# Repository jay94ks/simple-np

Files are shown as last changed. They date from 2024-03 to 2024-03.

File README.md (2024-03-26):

# Simple Number Pad
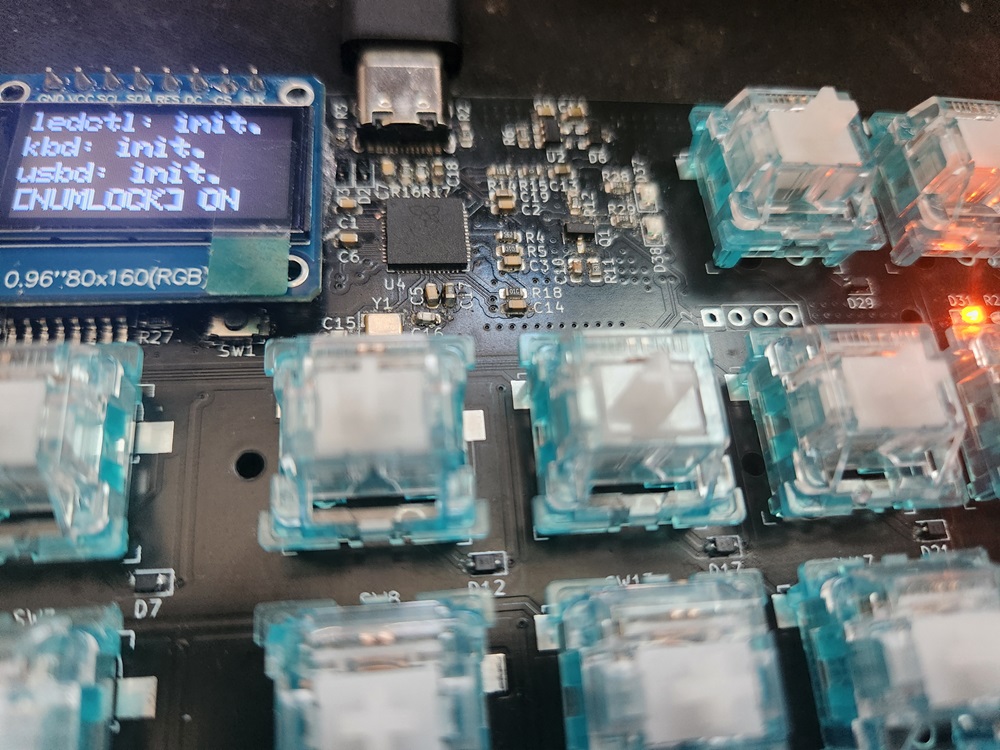
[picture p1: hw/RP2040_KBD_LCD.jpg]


### License
* This repository: MIT, partially GPL-v3 due to TFT library.
* TFT library: GPL-v3, [ST7735_TFT_PICO](https://github.com/gavinlyonsrepo/ST7735_TFT_PICO)

### Video


### Schematic
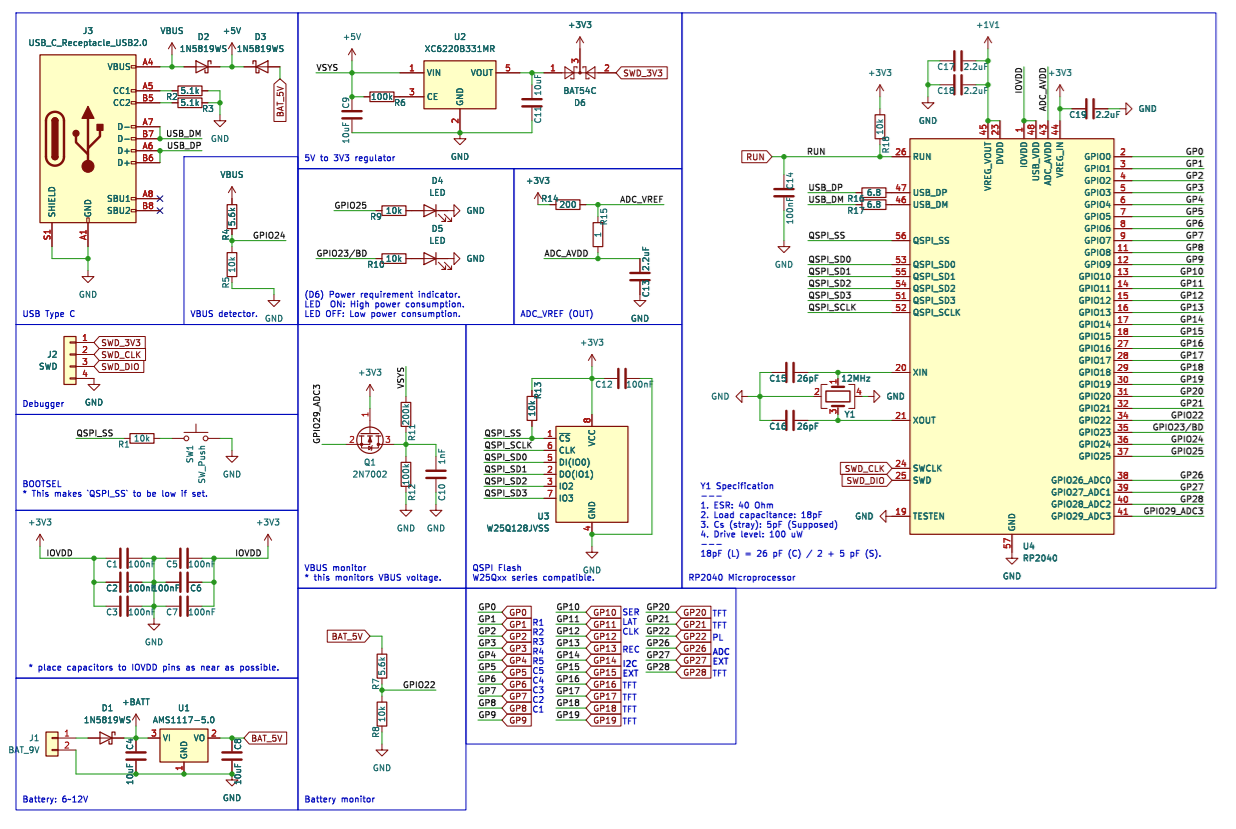
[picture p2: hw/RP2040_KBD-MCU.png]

See `hw/pdf/*.pdf` files to read more details.

### Features
* MCU: RP2040, 133MHz Dual core.
* 5 keys for user-defined functions.
* 17 keys for number pad.
* `TFT` display for calculator if no `HID` attached.
* 2 macro control keys, `RECORD` and `PLAY`.

### Plans for future features
* A flash memory to store user configurations? (currently, they're stored at `SRAM` of MCU only, so, volatile)
* I2C or SPI extension port?
* A little game that runs on the `TFT` display?
* Anything else...

### Firmware
Current planed features are implemented.
Now, calculator mode will be implemented soon.

### `tinyusb` RX callback.
Don't use `0.15.0` distribution that included on `pico-sdk`.
Update its branch to above version, then it works perfectly.

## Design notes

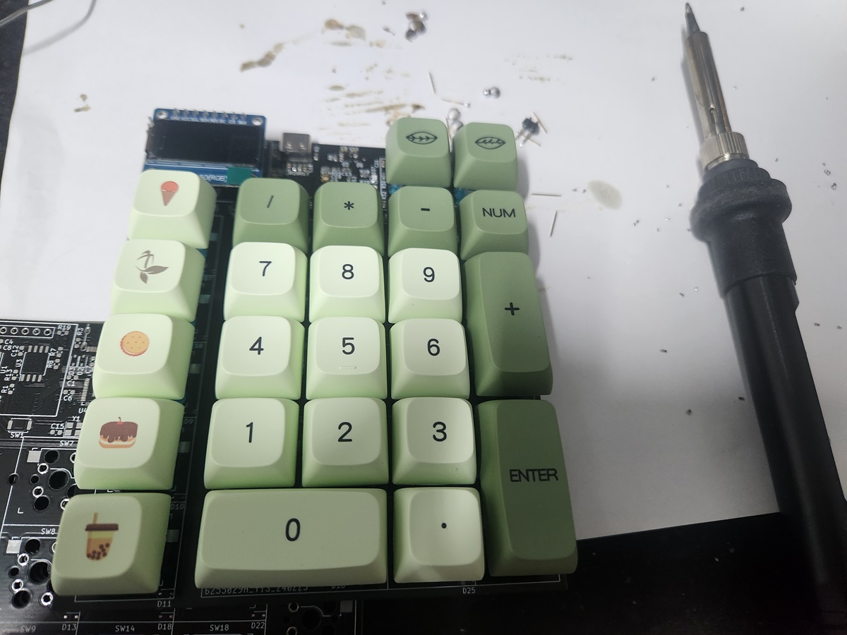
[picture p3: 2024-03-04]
hw/RP2040_KBD-IMG.jpg

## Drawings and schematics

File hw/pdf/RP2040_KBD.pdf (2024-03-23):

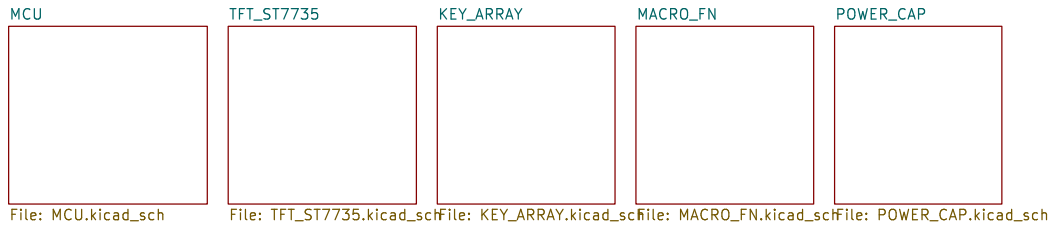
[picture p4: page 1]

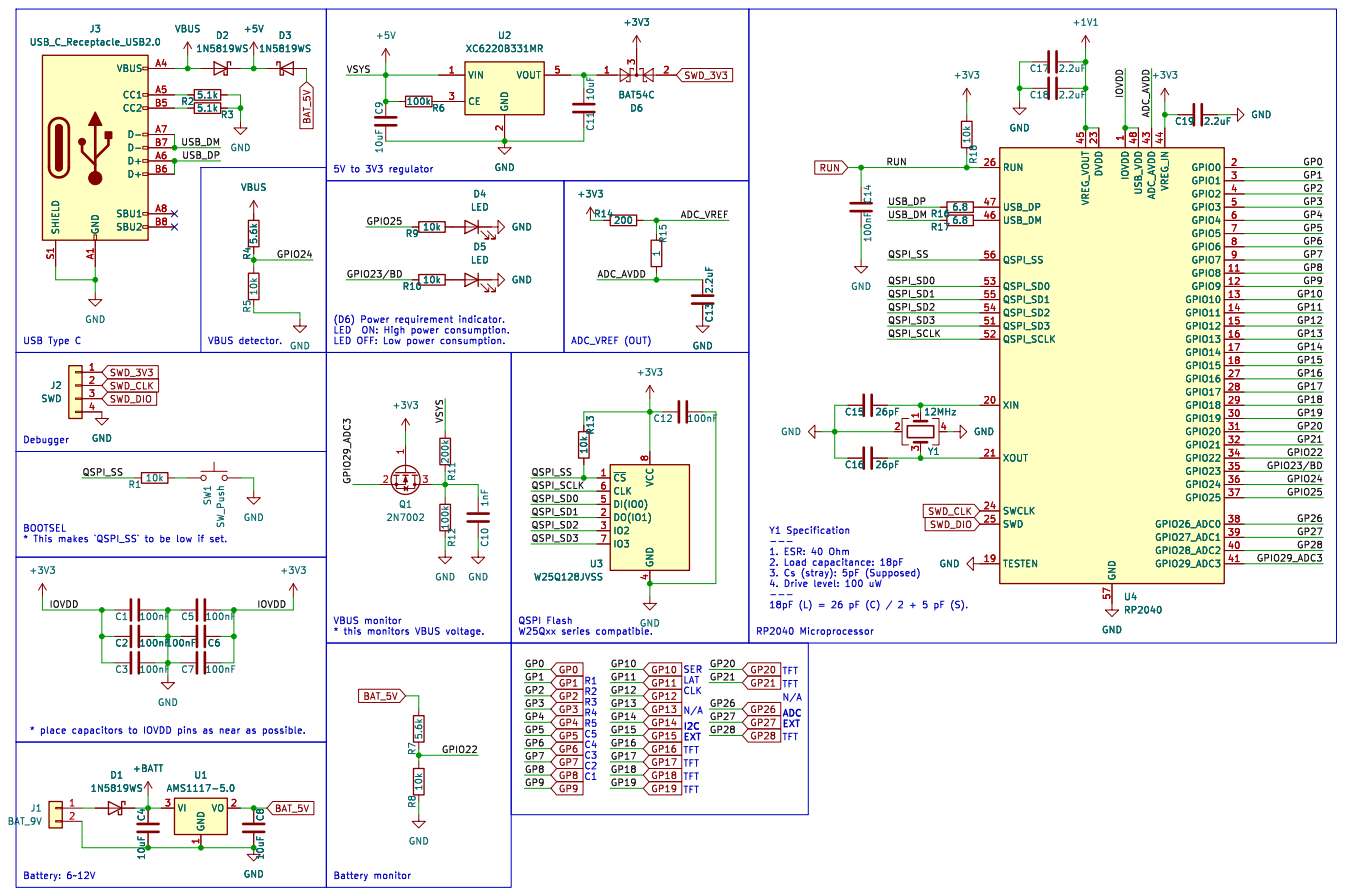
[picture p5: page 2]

1 GPIO8 11 GPIO9 12 GPIO10 13 GPIO11 14 GPIO12 15 GPIO13 16 GPIO14 17 GPIO15 18 TESTEN 19 GPIO0 2 XIN 20 XOUT 21 DVDD 23 SWCLK 24 SWD 25 RUN 26 GPIO16 27 GPIO17 28 GPIO18 29 GPIO1 3 GPIO19 30 GPIO20 31 GPIO21 32 GPIO22 34 GPIO23 35 GPIO24 36 GPIO25 37 GPIO26_ADC0 38 GPIO27_ADC1 39 GPIO2 4 GPIO28_ADC2 40 GPIO29_ADC3 41 ADC_AVDD 43 VREG_IN 44 VREG_VOUT 45 USB_DM 46 USB_DP 47 USB_VDD 48 GPIO3 5 QSPI_SD3 51 QSPI_SCLK 52 QSPI_SD0 53 QSPI_SD2 54 QSPI_SD1 55 QSPI_SS 56 GND 57 GPIO4 6 GPIO5 7 GPIO6 8 GPIO7 9 U4 RP2040 D1

1 GPIO8 11 GPIO9 12 GPIO10 13 GPIO11 14 GPIO12 15 GPIO13 16 GPIO14 17 GPIO15 18 TESTEN 19 GPIO0 2 XIN 20 XOUT 21 DVDD 23 SWCLK 24 SWD 25 RUN 26 GPIO16 27 GPIO17 28 GPIO18 29 GPIO1 3 GPIO19 30 GPIO20 31 GPIO21 32 GPIO22 34 GPIO23 35 GPIO24 36 GPIO25 37 GPIO26_ADC0 38 GPIO27_ADC1 39 GPIO2 4 GPIO28_ADC2 40 GPIO29_ADC3 41 ADC_AVDD 43 VREG_IN 44 VREG_VOUT 45 USB_DM 46 USB_DP 47 USB_VDD 48 GPIO3 5 QSPI_SD3 51 QSPI_SCLK 52 QSPI_SD0 53 QSPI_SD2 54 QSPI_SD1 55 QSPI_SS 56 GND 57 GPIO4 6 GPIO5 7 GPIO6 8 GPIO7 9 GND GND

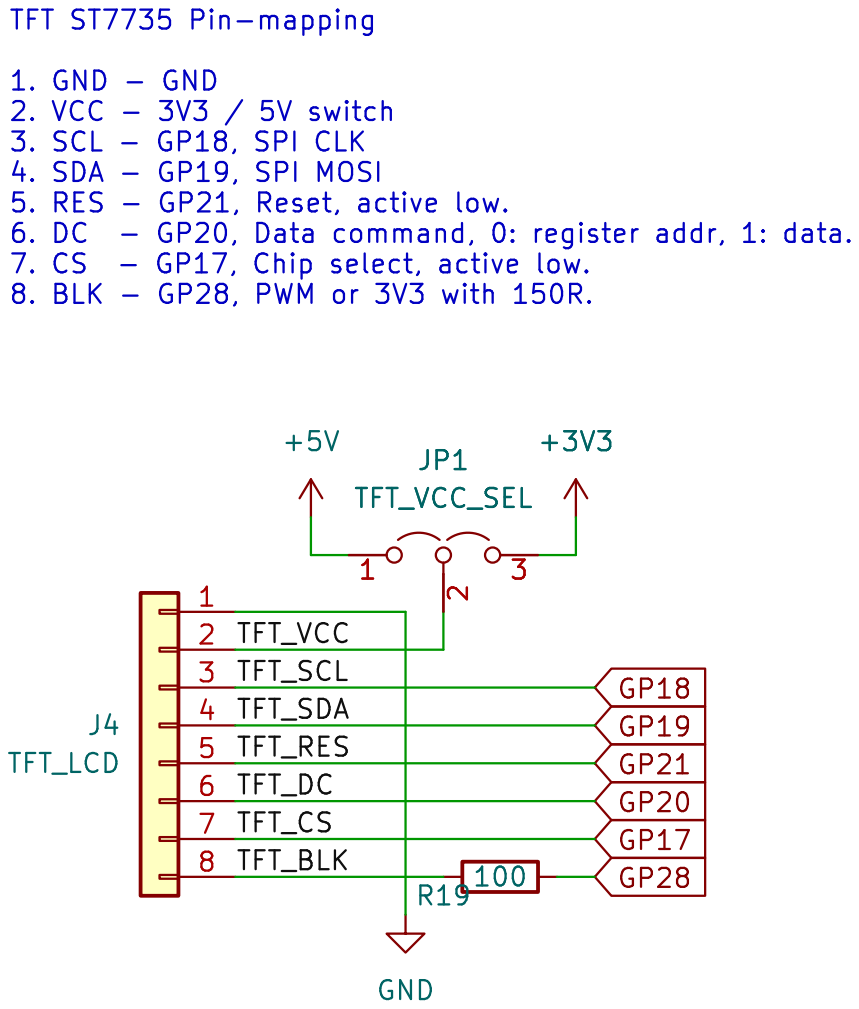
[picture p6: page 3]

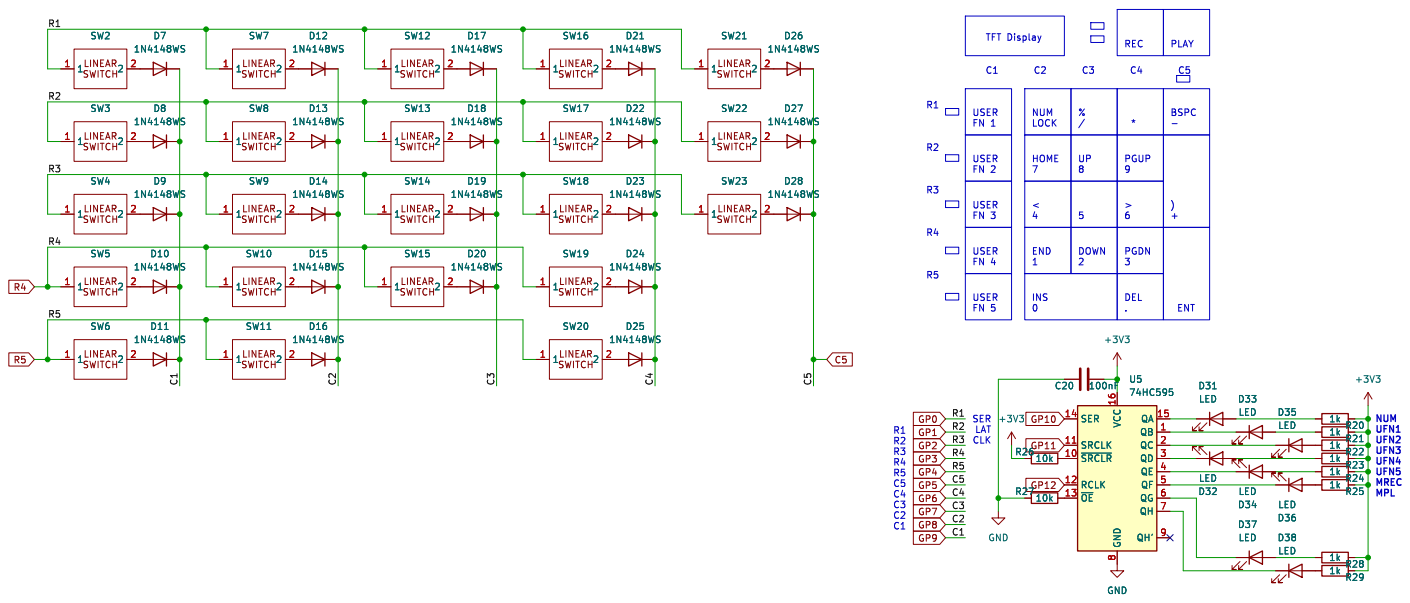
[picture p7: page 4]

BSPC - ENT DEL . USER

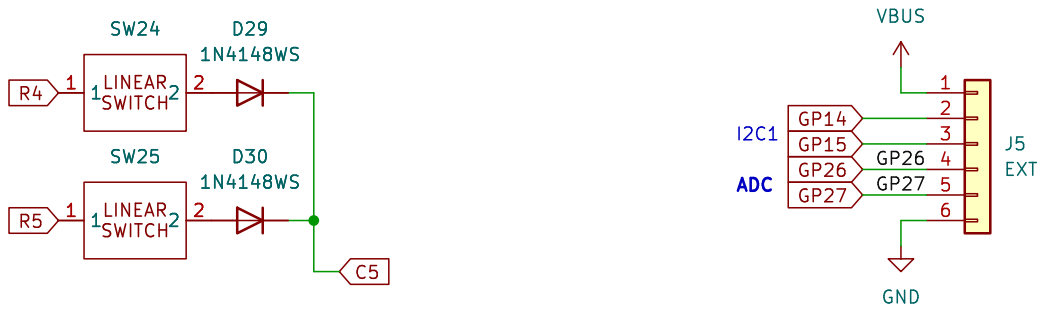
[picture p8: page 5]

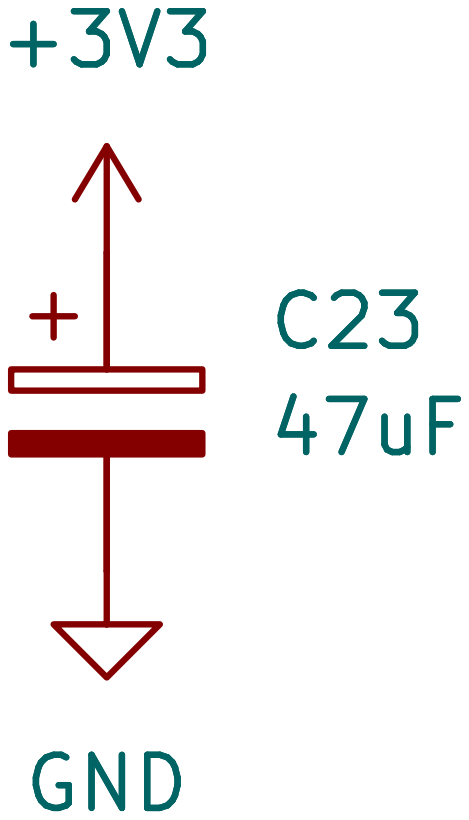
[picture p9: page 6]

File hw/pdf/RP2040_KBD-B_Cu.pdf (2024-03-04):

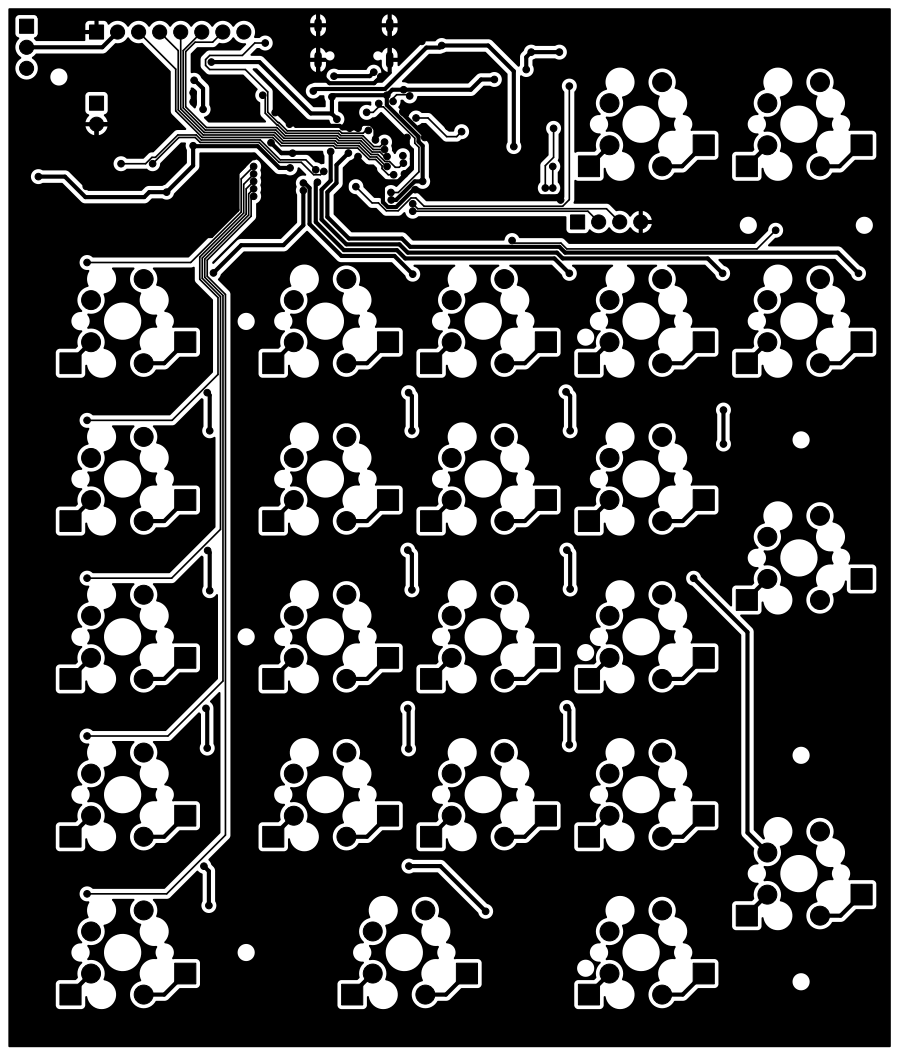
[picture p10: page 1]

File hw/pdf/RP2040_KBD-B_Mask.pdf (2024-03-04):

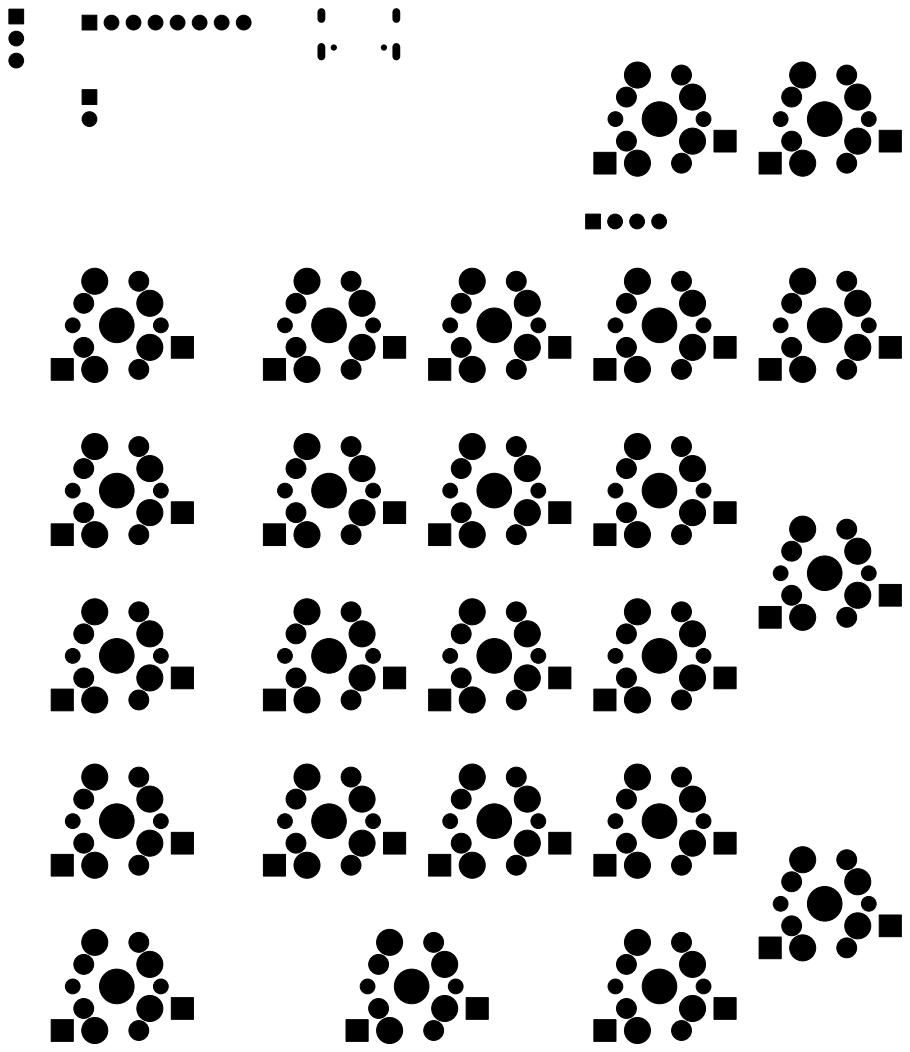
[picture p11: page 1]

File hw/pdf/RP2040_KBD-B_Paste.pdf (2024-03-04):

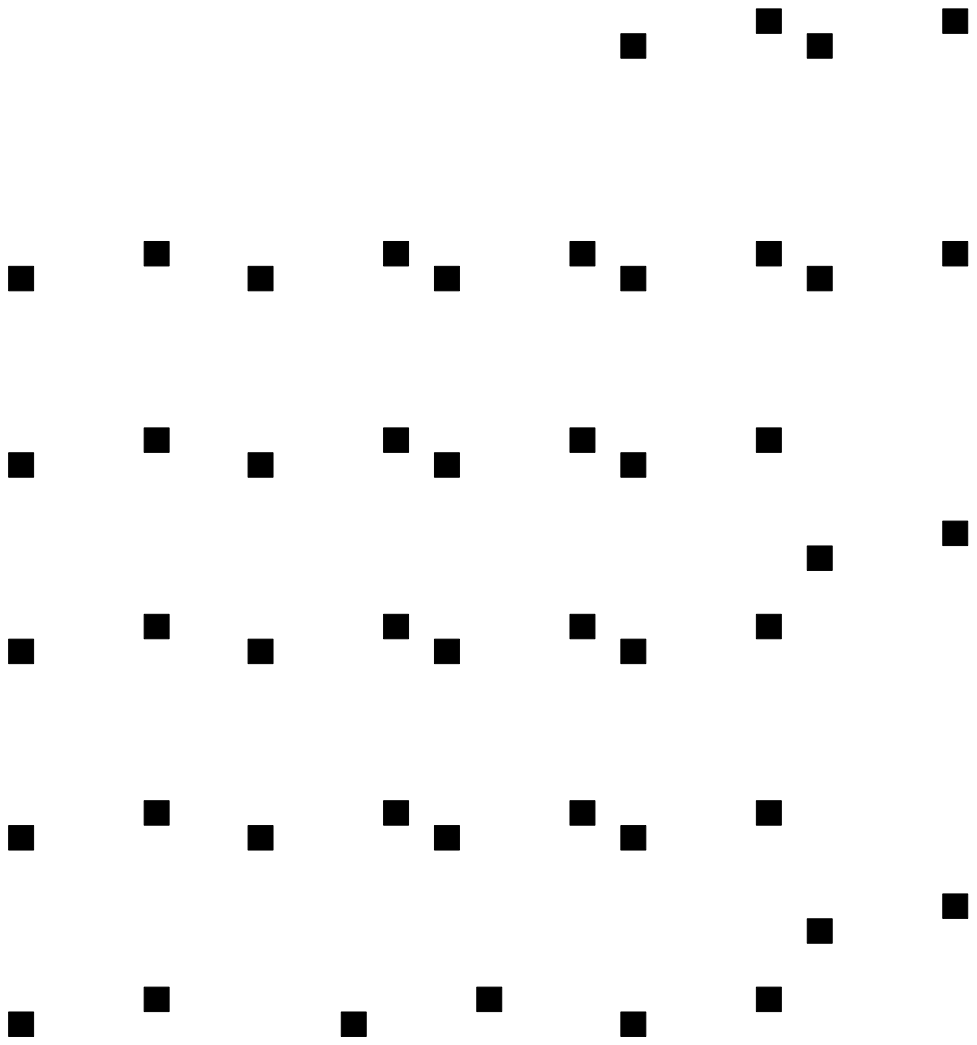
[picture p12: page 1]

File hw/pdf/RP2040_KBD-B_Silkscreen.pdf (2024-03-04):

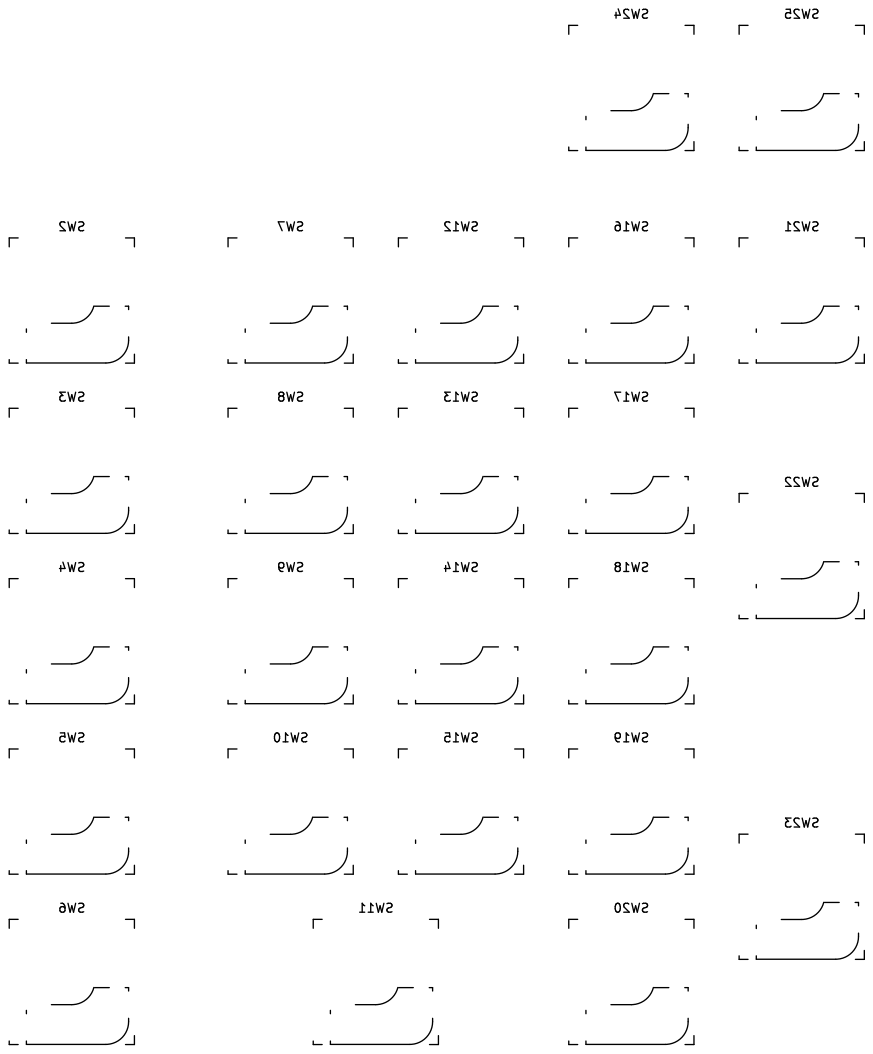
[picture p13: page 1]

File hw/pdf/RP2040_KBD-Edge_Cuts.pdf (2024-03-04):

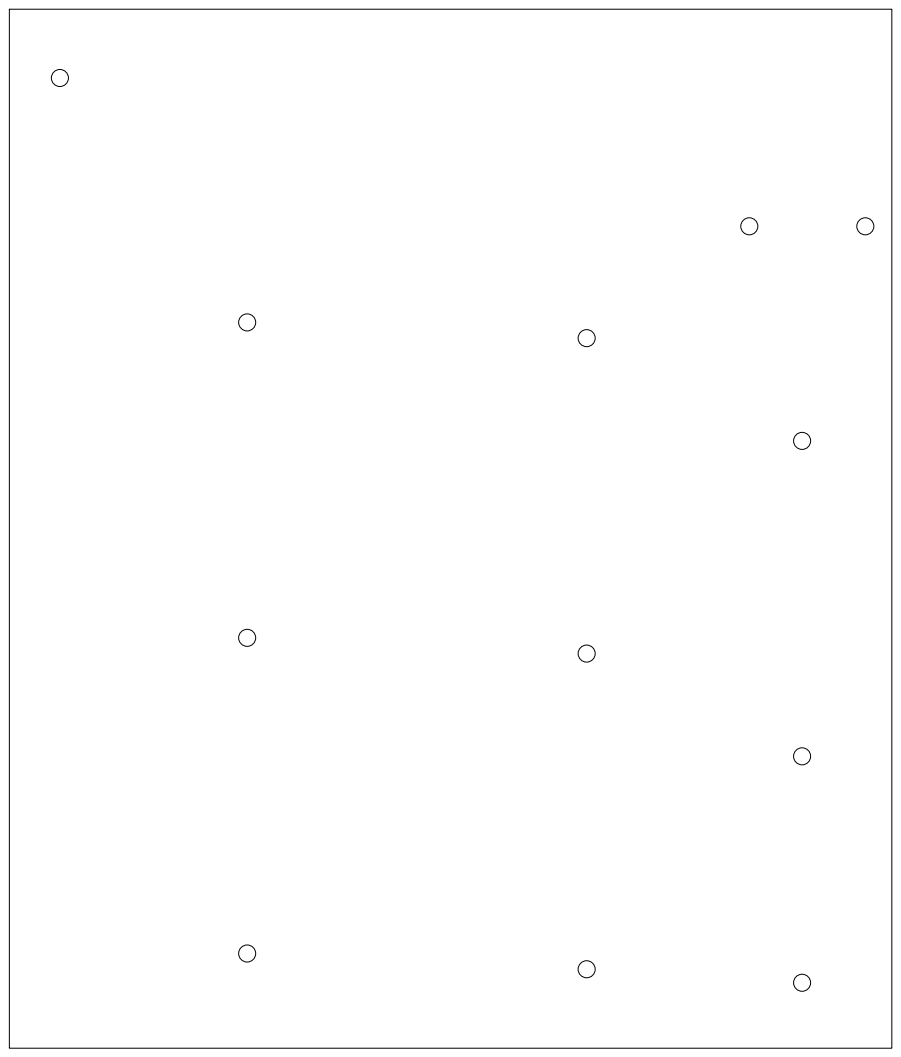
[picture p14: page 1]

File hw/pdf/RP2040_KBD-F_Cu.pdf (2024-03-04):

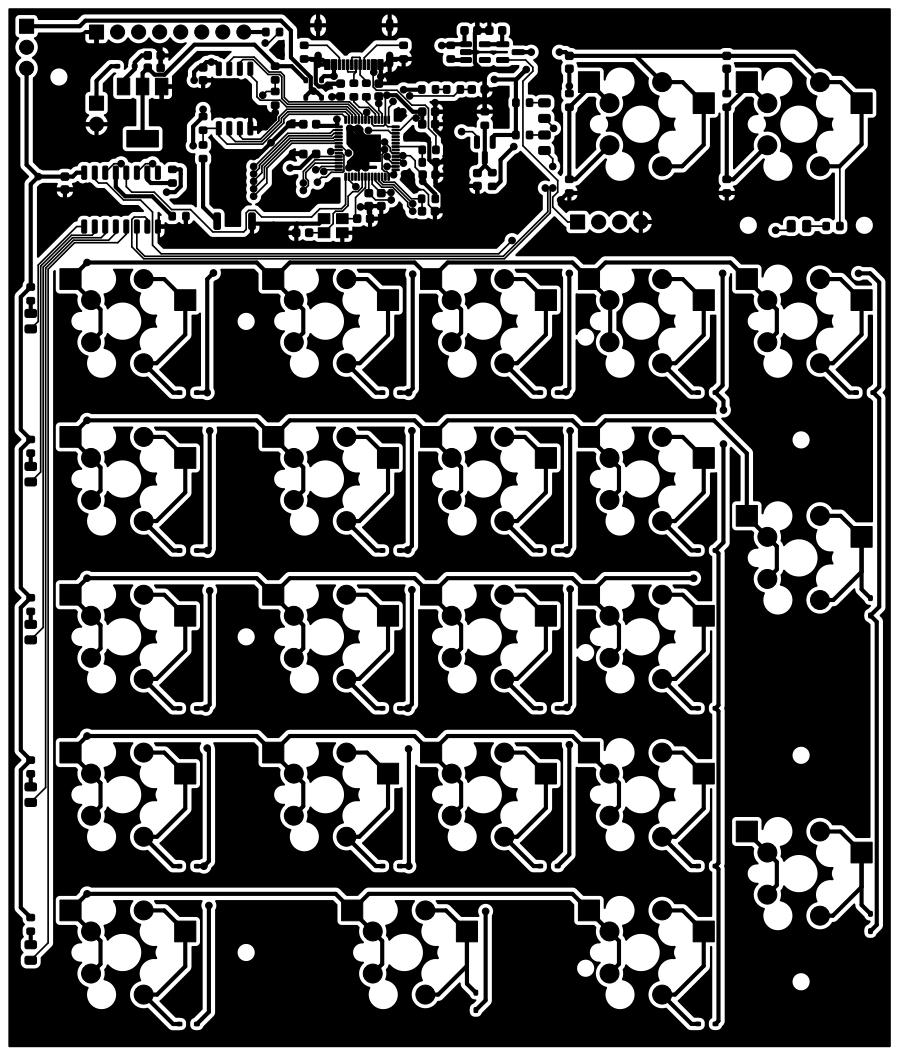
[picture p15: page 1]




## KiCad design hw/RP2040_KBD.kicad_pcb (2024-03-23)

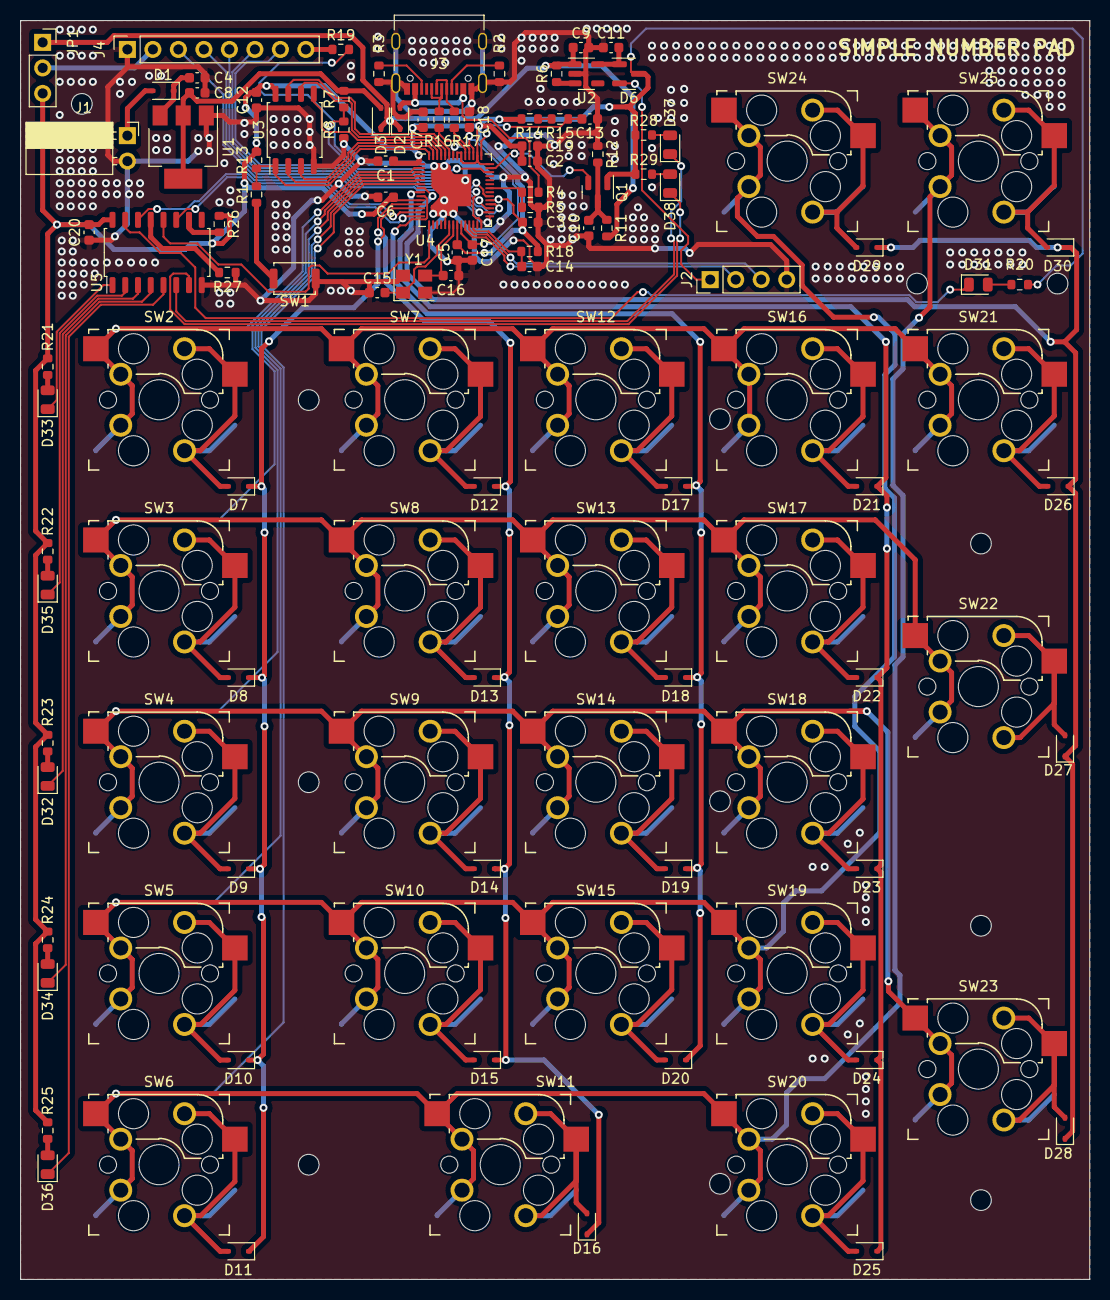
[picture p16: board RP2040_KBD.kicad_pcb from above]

Board: 2 copper layers, 106.5 x 125.4 mm, 120 parts (0 on the bottom side), 98 nets.

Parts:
C1, C2, C3, C5, C6, C7, C12, C14, C20: 100nF; C_0603_1608Metric
C4, C8, C9, C11: 10uF; C_0603_1608Metric
C10: 1nF; C_0603_1608Metric
C13, C17, C18, C19: 2.2uF; C_0603_1608Metric
C15, C16: 26pF; C_0603_1608Metric
D1, D2, D3: 1N5819WS; D_SOD-323
D6: BAT54C; SOT-23
D7, D8, D9, D10, D11, D12, D13, D14, D15, D16, D17, D18, D19, D20, D21, D22, D23, D24, D25, D26, D27, D28, D29, D30: 1N4148WS; D_SOD-323
D31, D32, D33, D34, D35, D36, D37, D38: LED; LED_0805_2012Metric
J1: BAT_9V; PinSocket_1x02_P2.54mm_Horizontal
J2: SWD; PinHeader_1x04_P2.54mm_Vertical
J3: USB_C_Receptacle_USB2.0; USB_C_Receptacle_Palconn_UTC16-G
J4: TFT_LCD; PinSocket_1x08_P2.54mm_Vertical
JP1: TFT_VCC_SEL; PinSocket_1x03_P2.54mm_Vertical
Q1: 2N7002; SOT-23
R1, R5, R8, R13, R18, R26, R27: 10k; R_0603_1608Metric
R2, R3: 5.1k; R_0603_1608Metric
R4, R7: 5.6k; R_0603_1608Metric
R6, R12: 100k; R_0603_1608Metric
R11: 200k; R_0603_1608Metric
R14: 200; R_0603_1608Metric
R15: 1; R_0603_1608Metric
R16, R17: 6.8; R_0603_1608Metric
R19: 100; R_0603_1608Metric
R20, R21, R22, R23, R24, R25, R28, R29: 1k; R_0603_1608Metric
SW1: SW_Push; SW_Push_SPST_NO_Alps_SKRK
SW2, SW3, SW4, SW5, SW6, SW7, SW8, SW9, SW10, SW11, SW12, SW13, SW14, SW15, SW16, SW17, SW18, SW19, SW20, SW21, SW22, SW23, SW24, SW25: Kailh_socket_MX_optional_reversible
U1: AMS1117-5.0; SOT-223-3_TabPin2
U2: XC6220B331MR; SOT-23-5
U3: W25Q128JVSS; SOIC-8_5.23x5.23mm_P1.27mm
U4: RP2040; QFN-56-1EP_7x7mm_P0.4mm_EP3.2x3.2mm
U5: 74HC595; SOP-16_4.55x10.3mm_P1.27mm
Y1: 12MHz; Crystal_SMD_3225-4Pin_3.2x2.5mm

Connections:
+1V1: C17.2, C18.2, U4.23 (DVDD), U4.45 (VREG_VOUT), U4.50 (DVDD)
+3V3: C1.1, C2.1, C3.1, C5.1, C6.1, C7.1, C12.1, C19.1, C20.2, D6.3, JP1.3 (B), Q1.1 (G), R13.1, R14.1, R18.2, R20.1, R21.1, R22.1, R23.1, R24.1, R25.1, R26.1, R28.1, R29.1, U3.8 (VCC), U4.1 (IOVDD), U4.10 (IOVDD), U4.22 (IOVDD), U4.33 (IOVDD), U4.42 (IOVDD), U4.44 (VREG_IN), U4.48 (USB_VDD), U4.49 (IOVDD), U5.16 (VCC)
+5V: C9.1, D2.1 (K), D3.1 (K), JP1.1 (A), R6.2, R11.2, U2.1 (VIN)
+BATT: C4.1, D1.1 (K), U1.3 (VI)
/MCU/ADC_AVDD: C13.2, R15.2, U4.43 (ADC_AVDD)
/MCU/ADC_VREF: R14.2, R15.1
/MCU/GPIO22: R7.1, R8.2, U4.34 (GPIO22)
/MCU/GPIO24: R4.1, R5.2, U4.36 (GPIO24)
/MCU/GPIO29_ADC3: Q1.2 (S), U4.41 (GPIO29_ADC3)
/MCU/QSPI_SCLK: U3.6 (CLK), U4.52 (QSPI_SCLK)
/MCU/QSPI_SD0: U3.5 (DI(IO0)), U4.53 (QSPI_SD0)
/MCU/QSPI_SD1: U3.2 (DO(IO1)), U4.55 (QSPI_SD1)
/MCU/QSPI_SD2: U3.3 (IO2), U4.54 (QSPI_SD2)
/MCU/QSPI_SD3: U3.7 (IO3), U4.51 (QSPI_SD3)
/MCU/QSPI_SS: R1.1, R13.2, U3.1 (~CS), U4.56 (QSPI_SS)
/MCU/USB_DM: J3.A7 (D-), J3.B7 (D-), R17.1
/MCU/USB_DP: J3.A6 (D+), J3.B6 (D+), R16.1
/TFT_ST7735/TFT_BLK: J4.8, R19.1
/TFT_ST7735/TFT_VCC: J4.2, JP1.2 (C)
BAT_5V: C8.1, D3.2 (A), R7.2, U1.2 (VO)
C5: D26.1 (K), D27.1 (K), D28.1 (K), D29.1 (K), D30.1 (K), U4.7 (GPIO5)
GND: C1.2, C2.2, C3.2, C4.2, C5.2, C6.2, C7.2, C8.2, C9.2, C10.1, C11.1, C12.2, C13.1, C14.2, C15.1, C16.1, C17.1, C18.1, C19.2, C20.1, J1.2, J2.4, J3.A1 (GND), J3.A12 (GND), J3.B1 (GND), J3.B12 (GND), J3.S1 (SHIELD), J4.1, R2.2, R3.1, R5.1, R8.1, R12.1, R27.1, SW1.1, U1.1 (GND), U2.2 (GND), U3.4 (GND), U4.19 (TESTEN), U4.57 (GND), U5.8 (GND), Y1.2, Y1.4
GP0: SW2.1, SW7.1, SW12.1, SW16.1, SW21.1, U4.2 (GPIO0)
GP1: SW3.1, SW8.1, SW13.1, SW17.1, SW22.1, U4.3 (GPIO1)
GP2: SW4.1, SW9.1, SW14.1, SW18.1, SW23.1, U4.4 (GPIO2)
GP3: SW5.1, SW10.1, SW15.1, SW19.1, SW24.1, U4.5 (GPIO3)
GP4: SW6.1, SW11.1, SW20.1, SW25.1, U4.6 (GPIO4)
GP6: D21.1 (K), D22.1 (K), D23.1 (K), D24.1 (K), D25.1 (K), U4.8 (GPIO6)
GP7: D17.1 (K), D18.1 (K), D19.1 (K), D20.1 (K), U4.9 (GPIO7)
GP8: D12.1 (K), D13.1 (K), D14.1 (K), D15.1 (K), D16.1 (K), U4.11 (GPIO8)
GP9: D7.1 (K), D8.1 (K), D9.1 (K), D10.1 (K), D11.1 (K), U4.12 (GPIO9)
GP10: U4.13 (GPIO10), U5.14 (SER)
GP11: U4.14 (GPIO11), U5.11 (SRCLK)
GP12: U4.15 (GPIO12), U5.12 (RCLK)
GP17: J4.7, U4.28 (GPIO17)
GP18: J4.3, U4.29 (GPIO18)
GP19: J4.4, U4.30 (GPIO19)
GP20: J4.6, U4.31 (GPIO20)
GP21: J4.5, U4.32 (GPIO21)
GP28: R19.2, U4.40 (GPIO28_ADC2)
unnamed: D1.2 (A), J1.1
unnamed: D7.2 (A), SW2.2
unnamed: D8.2 (A), SW3.2
unnamed: D9.2 (A), SW4.2
unnamed: D10.2 (A), SW5.2
unnamed: D11.2 (A), SW6.2
unnamed: D12.2 (A), SW7.2
unnamed: D13.2 (A), SW8.2
unnamed: D14.2 (A), SW9.2
unnamed: D15.2 (A), SW10.2
unnamed: D16.2 (A), SW11.2
unnamed: D17.2 (A), SW12.2
unnamed: D18.2 (A), SW13.2
unnamed: D19.2 (A), SW14.2
unnamed: D20.2 (A), SW15.2
unnamed: D21.2 (A), SW16.2
unnamed: D22.2 (A), SW17.2
unnamed: D23.2 (A), SW18.2
unnamed: D24.2 (A), SW19.2
unnamed: D25.2 (A), SW20.2
unnamed: D26.2 (A), SW21.2
unnamed: D27.2 (A), SW22.2
unnamed: D28.2 (A), SW23.2
unnamed: D29.2 (A), SW24.2
unnamed: D30.2 (A), SW25.2
unnamed: D31.2 (A), R20.2
unnamed: D31.1 (K), U5.15 (QA)
unnamed: D32.2 (A), R23.2
unnamed: D32.1 (K), U5.3 (QD)
unnamed: D33.2 (A), R21.2
unnamed: D33.1 (K), U5.1 (QB)
unnamed: D34.2 (A), R24.2
unnamed: D34.1 (K), U5.4 (QE)
unnamed: D35.2 (A), R22.2
unnamed: D35.1 (K), U5.2 (QC)
unnamed: D36.2 (A), R25.2
unnamed: D36.1 (K), U5.5 (QF)
unnamed: D37.2 (A), R28.2
unnamed: D37.1 (K), U5.6 (QG)
unnamed: D38.2 (A), R29.2
unnamed: D38.1 (K), U5.7 (QH)
unnamed: J3.A5 (CC1), R2.1
unnamed: J3.B5 (CC2), R3.2
unnamed: C10.2, Q1.3 (D), R11.1, R12.2
unnamed: R1.2, SW1.2
unnamed: R6.1, U2.3 (CE)
unnamed: C11.2, D6.1, U2.5 (VOUT)
unnamed: R17.2, U4.46 (USB_DM)
unnamed: R16.2, U4.47 (USB_DP)
unnamed: C15.2, U4.20 (XIN), Y1.1
unnamed: C16.2, U4.21 (XOUT), Y1.3
unnamed: R27.2, U5.13 (~OE)
unnamed: R26.2, U5.10 (~SRCLR)
RUN: C14.1, R18.1, U4.26 (RUN)
SWD_3V3: D6.2, J2.1
SWD_CLK: J2.2, U4.24 (SWCLK)
SWD_DIO: J2.3, U4.25 (SWD)
VBUS: D2.2 (A), J3.A4 (VBUS), J3.A9 (VBUS), J3.B4 (VBUS), J3.B9 (VBUS), R4.2

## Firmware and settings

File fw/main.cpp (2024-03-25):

#include "kbd/kbd.h"
#include "tft/tft.h"
#include "board/ledctl.h"
#include "board/usbd.h"
#include "task/taskqueue.h"
#include "mode/mode.h"
#include "pico/stdlib.h"
#include <tusb.h>

int main(void) {
    tty_print("tft: init.\n");
    TaskQueue::prepare();

    Kbd* kbd = Kbd::get();
    tty_print("kbd: init.\n");

    Ledctl* led = Ledctl::get();
    tty_print("led: init.\n");

    Usbd* usbd = Usbd::get();
    if (!usbd->init()) {
        tty_print("usb: fatal.\n");
        
        while(true) {
            led->toggle(ELED_MREC);
            sleep_ms(250);
        }
    }

    // --> try to enter default mode.
    IMode::trySetCurrent(nullptr);
    while(true) {
        kbd->scanOnce();
        led->updateOnce();
        usbd->stepOnce();
        
        // --> calls mode-specific stepper routine.
        if (IMode* mode = IMode::getCurrent()) {
            mode->stepOnce();
        }
    }
}

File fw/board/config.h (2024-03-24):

#ifndef __BOARD_CONFIG_H__
#define __BOARD_CONFIG_H__

// --> report ID for keyboard.
#define RID_KEYBOARD 1

enum {

    GPIO_KBD_ROW_1 = 0,
    GPIO_KBD_ROW_2 = 1,
    GPIO_KBD_ROW_3 = 2,
    GPIO_KBD_ROW_4 = 3,
    GPIO_KBD_ROW_5 = 4,

    GPIO_KBD_COL_5 = 5,
    GPIO_KBD_COL_4 = 6,
    GPIO_KBD_COL_3 = 7,
    GPIO_KBD_COL_2 = 8,
    GPIO_KBD_COL_1 = 9,

    GPIO_HC595_SER = 10,
    GPIO_HC595_CLK = 11,
    GPIO_HC595_LAT = 12,

    GPIO_TFT_RST = 21,
    GPIO_TFT_DC = 20,
    GPIO_TFT_CS = 17,
    GPIO_TFT_CLK = 18,
    GPIO_TFT_DAT = 19,

    GPIO_TFT_BACKLIGHT_PWM = 28,
};

#endif

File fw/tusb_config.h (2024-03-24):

#ifdef __cplusplus
#ifndef CFG_TUD_EXTERN
#define CFG_TUD_EXTERN  extern "C"
#endif
 extern "C" {
#else
#ifndef CFG_TUD_EXTERN
#define CFG_TUD_EXTERN  extern
#endif
#endif

//--------------------------------------------------------------------
// COMMON CONFIGURATION
//--------------------------------------------------------------------

// defined by board.mk
#ifndef CFG_TUSB_MCU
  #error CFG_TUSB_MCU must be defined
#endif

// RHPort number used for device can be defined by board.mk, default to port 0
#ifndef BOARD_DEVICE_RHPORT_NUM
  #define BOARD_DEVICE_RHPORT_NUM     0
#endif

// RHPort max operational speed can defined by board.mk
// Default to Highspeed for MCU with internal HighSpeed PHY (can be port specific), otherwise FullSpeed
#ifndef BOARD_DEVICE_RHPORT_SPEED
  #if (CFG_TUSB_MCU == OPT_MCU_LPC18XX || CFG_TUSB_MCU == OPT_MCU_LPC43XX || CFG_TUSB_MCU == OPT_MCU_MIMXRT10XX || \
       CFG_TUSB_MCU == OPT_MCU_NUC505  || CFG_TUSB_MCU == OPT_MCU_CXD56 || CFG_TUSB_MCU == OPT_MCU_SAMX7X)
    #define BOARD_DEVICE_RHPORT_SPEED   OPT_MODE_HIGH_SPEED
  #else
    #define BOARD_DEVICE_RHPORT_SPEED   OPT_MODE_FULL_SPEED
  #endif
#endif

// Device mode with rhport and speed defined by board.mk
#if   BOARD_DEVICE_RHPORT_NUM == 0
  #define CFG_TUSB_RHPORT0_MODE     (OPT_MODE_DEVICE | BOARD_DEVICE_RHPORT_SPEED)
#elif BOARD_DEVICE_RHPORT_NUM == 1
  #define CFG_TUSB_RHPORT1_MODE     (OPT_MODE_DEVICE | BOARD_DEVICE_RHPORT_SPEED)
#else
  #error "Incorrect RHPort configuration"
#endif

#ifndef CFG_TUSB_OS
#define CFG_TUSB_OS               OPT_OS_NONE
#endif

// CFG_TUSB_DEBUG is defined by compiler in DEBUG build
// #define CFG_TUSB_DEBUG           0

/* USB DMA on some MCUs can only access a specific SRAM region with restriction on alignment.
 * Tinyusb use follows macros to declare transferring memory so that they can be put
 * into those specific section.
 * e.g
 * - CFG_TUSB_MEM SECTION : __attribute__ (( section(".usb_ram") ))
 * - CFG_TUSB_MEM_ALIGN   : __attribute__ ((aligned(4)))
 */
#ifndef CFG_TUSB_MEM_SECTION
#define CFG_TUSB_MEM_SECTION
#endif

#ifndef CFG_TUSB_MEM_ALIGN
#define CFG_TUSB_MEM_ALIGN          __attribute__ ((aligned(4)))
#endif

//--------------------------------------------------------------------
// DEVICE CONFIGURATION
//--------------------------------------------------------------------

#ifndef CFG_TUD_ENDPOINT0_SIZE
#define CFG_TUD_ENDPOINT0_SIZE    64
#endif

//------------- CLASS -------------//
#define CFG_TUD_HID               1
#define CFG_TUD_MSC               0
#define CFG_TUD_MIDI              0
#define CFG_TUD_CDC               1
#define CFG_TUD_VENDOR            0

// HID buffer size Should be sufficient to hold ID (if any) + Data
#define CFG_TUD_HID_EP_BUFSIZE    16

// CDC FIFO size of TX and RX
#define CFG_TUD_CDC_RX_BUFSIZE    64 //(TUD_OPT_HIGH_SPEED ? 512 : 64)
#define CFG_TUD_CDC_TX_BUFSIZE    64 //(TUD_OPT_HIGH_SPEED ? 512 : 64)

#ifdef __cplusplus
 }

#endif

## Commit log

2024-03-04 Initial commit.
    [KEY_ARRAY.kicad_sch, MACRO_FN.kicad_sch, MCU.kicad_sch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]
2024-03-18 Schematic updated.
    [KEY_ARRAY.kicad_sch, MACRO_FN.kicad_sch, MCU.kicad_sch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]
2024-03-20 FW: implemented simple CDC-based control protocol and corrected numlock LED indicator.
    [keymap.cpp, ledctl.cpp]
2024-03-23 schematic PDF file updated.
2024-03-23 gerber files are regenerated
    [RP2040_KBD-B_Cu.gbr, RP2040_KBD-B_Mask.gbr, RP2040_KBD-B_Paste.gbr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]
2024-03-24 Implemented asynchronous framework
2024-03-24 switching `fw` and `fw_refactor` files.
2024-03-24 Refactoring completed, but `CDC RX` doesn't work :angry:
    [basic.cpp]
2024-03-25 solved warnings and added welcome mode to display splash.
    [tft.cpp]
